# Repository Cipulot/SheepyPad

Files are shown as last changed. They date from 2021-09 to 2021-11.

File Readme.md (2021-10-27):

# SheepyPad

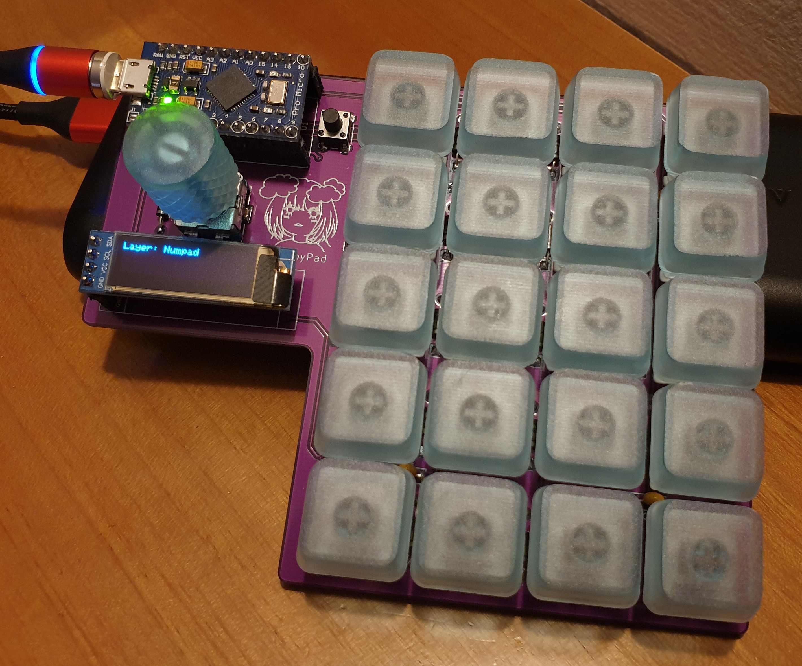
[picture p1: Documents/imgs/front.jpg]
SheepyPad


SheepyPad is an ISO Enter shaped macropad easy to build and customize.

Main features included:

- 5x4 key matrix (both 3-pin and 5-pin supported)
- 128x32 OLED display for status indication
- Rotary encoder for media control
- Integrated 2 operand calculator with basic math operations (+, -, *, /, sqrt)
- VIA and QMK compatibility
- 6 addressable RGB LEDs for underglow

## Guides

### QMK

This board fully supports QMK, refer to the [official docs](https://beta.docs.qmk.fm/).

### VIA

If you wanna use VIA follow the instructions [here](https://github.com/Cipulot/SheepyPad/blob/main/Documents/via.md).

### Calculator

SheepyPad implements a simple calculator that you can use to perform basic math operations. Follow the [Calculator Guide](https://github.com/Cipulot/SheepyPad/blob/main/Documents/calculator.md) to get started.

### PCB

Follow the [PCB Assembly Instructions](https://github.com/Cipulot/SheepyPad/blob/main/Documents/pcb_assembly.md) to build the PCB and test it out.

## Repo structure

- `Docs` contains all documentation and images for the project.
- `Firmware` contains both the source and precompiled binaries.
- `Hardware` contains the KiCad design files for the keyboard, fabrication files (in the [Gerbers](https://github.com/Cipulot/SheepyPad/blob/main/Hardware/Gerbers) folder).
- `Mechanicals` contains STEP file of the PCB and components, plate and case files.

## Project status

Project is currently in development. V1 boards have been produced and tested successfully. V2 boards are in the works and will add/change currently available features (both hardware and firmware wise).

Software is in constant change and being updated on my qmk_firmware fork available [here](https://github.com/Cipulot/qmk_firmware). You can find a basic default code example (with precompiled binaries) in this repo too if you want to quickly get it up and running.

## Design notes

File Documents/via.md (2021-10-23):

# VIA Keymap Configuration

VIA is a great way to quickly configure both keymap and lighting for the SheepyPad. Rather than modify code, recompile and then flash the binary, you can simply change the keymap and lighting settings in the graphical editor.

## Install VIA

To use VIA, first [download and install](https://caniusevia.com/) the configuration software.

After that you'll need to go to the `Settings` tab and select `Show Design tab` as shown here:

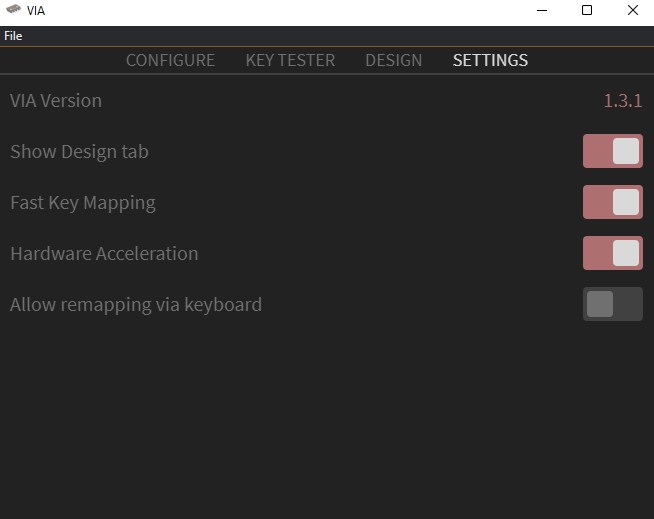
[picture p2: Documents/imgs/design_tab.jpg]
DesignTab


After that the `Design` tab will appear on the top center of the VIA window.

Now click on it and you'll be presented with this window:

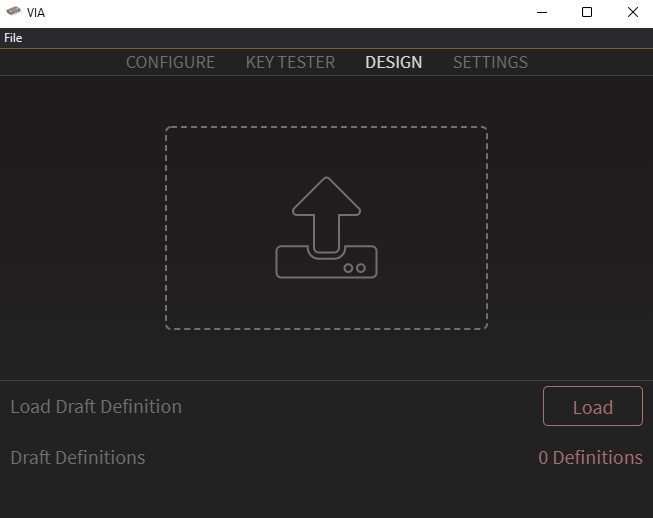
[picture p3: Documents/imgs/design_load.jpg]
DesignLoad


Click on either `Load` or the big icon in the center of the window to load the SheepyPad definition `json` file. This file is located in the `Firmware` folder, the [info.json](https://github.com/Cipulot/SheepyPad/blob/main/Firmware/info.json) file to be specific.

If everything loaded correctly you're gonna see something like this:

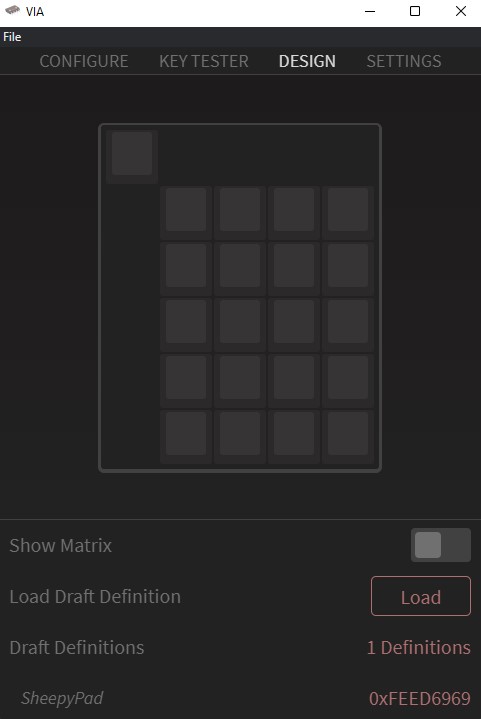
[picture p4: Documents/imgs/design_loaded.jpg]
DesignLoaded


**Note: in order to edit the keymap and lighting you MUST follow the procedure listed above. VIA does not automatically recognize SheepyPad.**

## Configure Keys

From within VIA, you can easily configure keys as you please. It allows you to change the default keymap to whatever suits your needs. Every key (with **one exemption** shown later) on every layer can be reconfigured.

The default configuration is as follows:

- Numberpad
- Empty Macro ---> here you have the freedom to assign macros or whatever you want
- Calculator  ---> here the keys have custom coded keycodes that are not standard
- Adjust      ---> here you have all the QMK keycodes to control lighting and other features

**It does not however allow you to configure the rotary encoder behavior......yet, a workaround is in the making but for now you'll need to configure them through QMK**.

### Exemption

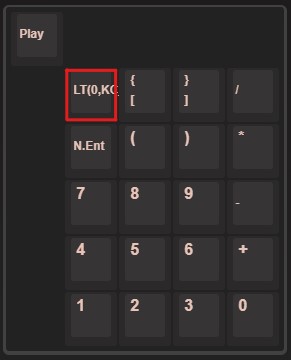
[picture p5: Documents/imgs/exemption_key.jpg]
ExemptionKey


In order to switch layer in a "cycle style" this key is used. Changing the layer is done by pressing this key repeatedly. Changing it using VIA will probably cause the board to be stuck in the last layer selected untill the board is unpluggged and replugged. This is a known thing and will be changed in the future.

## Configure Encoders

By default, the encoders are configured to volume up / down (on every layer).

Unfortunately, due to limitations in VIA the encoders are not visible or configurable. The best workaround at this time is to build a new VIA keymap with the encoder functions altered to suit your use case, flash this onto the board, and then configure the remainder of the keys in VIA. This can be done by following the below instructions:

- Follow the QMK [getting started guide](https://docs.qmk.fm/#/newbs_getting_started) to install the toolchain and configure your build environment.
- Open the `../via/keymap.c` file in your preferred text editor.
- Locate the function `encoder_update_user`, and update the keycodes in `tap_code(KC_xxx)` to one from the [keycodes list](https://beta.docs.qmk.fm/using-qmk/simple-keycodes/keycodes). If you use keycode not on the basic list, you may need to replace `tap_code` with `tap_code16`.
- With the changes made, save your new keymap, build, and flash the keymap to SheepyPad.
- You should now see the encoders functioning as desired, and you can configure the remainder or your keyboard using VIA.

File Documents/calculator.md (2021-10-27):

# Calculator Guide

The calculator is integrated and can be accessed by toggling the layer key until you see the following on the OLED screen:

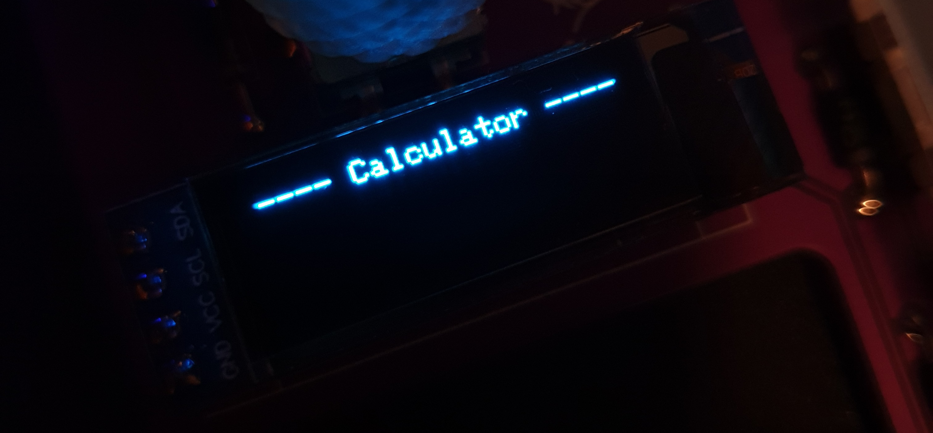
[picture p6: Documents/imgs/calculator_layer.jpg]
CalculatorLayer


From here the key matrix acts as the input method for the calculator, following this mapping:

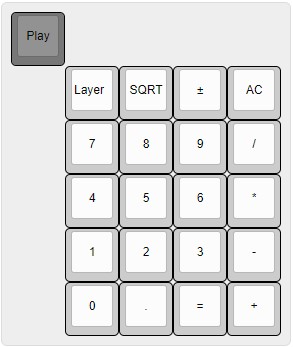
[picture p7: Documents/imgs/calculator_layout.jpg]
CalculatorLayout


## Supported operands and operations

The calculator supports 2 operands , called `term_1` and `term_2` in the code (for reference). A series of checks is implemented so that the state of the calculator is always valid.

### 4 basic operations and signs

The input flow is as follows for the 4 basic operations:

1. user enters digits for `term_1`

    1.1 user presses `±` to change `term_1` sing

2. user selects an operation `+` , `-` , `*` or `/`

3. user enters digits for `term_2`

    3.1 user presses `±` to change `term_2` sing

4. user presses `=` to calculate the result

When the calculation result is displayed, the calculator will wait for the user to reset the state to the initial state via the `AC` key.

**Note:** if an operation is selected before any digit has being pressed the calculator treats `term_1` as a `0`. In this case when `*` or `/` is selected the return value will be `0` as the result. The indetermination case is also handled, returning `0`.

### Square Root

The `SQRT` function calculates the square root of the `term_1` operand by itself or the result of an operation between `term_1` and `term_2`. Therefore the `term_1` operand or the result of the operation between `term_1` and `term_2` must be a positive number, otherwise the calculator will display `Imaginary Root!` as a result.

The input flow is as follows:

**`term_1` only**

1. user enters digits for `term_1`

2. user presses `SQRT` to calculate the result

**`term_1` and `term_2`**

1. user enters digits for `term_1`

    1.1 user presses `±` to change `term_1` sing

2. user selects an operation `+` , `-` , `*` or `/`

3. user enters digits for `term_2`

    3.1 user presses `±` to change `term_2` sing

4. user presses `SQRT` to calculate the result, evaluated as `sqrt( term_1|operand|term_2)`

As for the 4 basic operations, when the calculation result is displayed, the calculator will wait for the user to reset the state to the initial state via the `AC` key.

#### **Notes:**

~~* The `SQRT` function is not supported for `term_2` operands. If you try to execute one of the 4 basic operations and then press `SQRT` this won't produce any output (the `SQRT` command is ignored).~~

~~* Again if no digits are entered for `term_1` the calculator will treat it as a `0` and return `0` as the result if `SQRT` is pressed.~~

~~**Implementation of the `SQRT` function as above (`term1` → `operation` → `term__2` → `SQRT`) is in the work.**~~

## Implementation status

This table summarize the implementation status of the calculator.

| **Legend:**  | ✅ Supported | 🚧 Under Development | 💡 Planned |
|-|-|-|-|

| Feature | Status |
|:---:|:---:|
| `+` | ✅ |
| `-` | ✅ |
| `*` | ✅ |
| `/` | ✅ |
| `±` | ✅ |
| `AC` | ✅ |
| `SQRT` | ✅ |
| `C` | 💡 |
| `.` aka decimal operands | 🚧 |

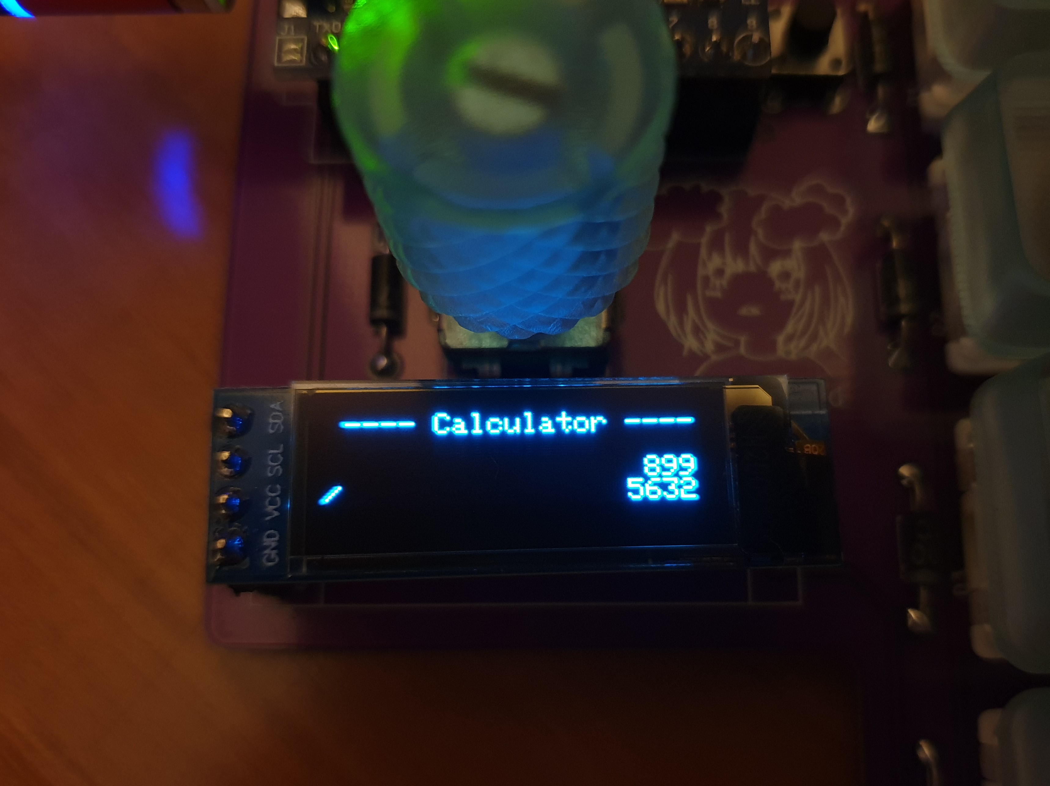
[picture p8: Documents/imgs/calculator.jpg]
Calculator


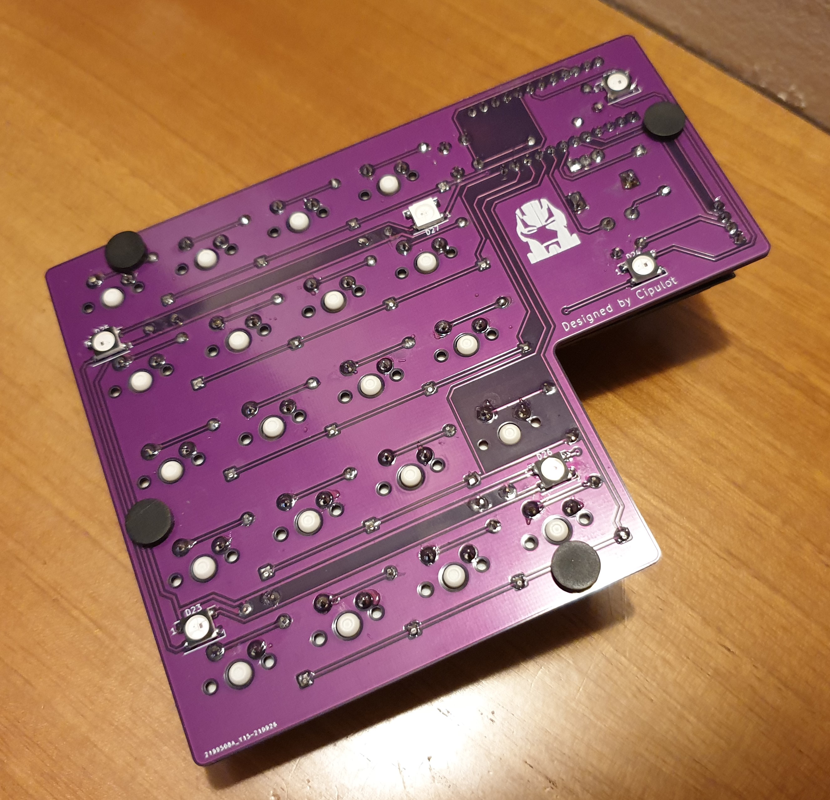
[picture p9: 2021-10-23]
Documents/imgs/back.jpg

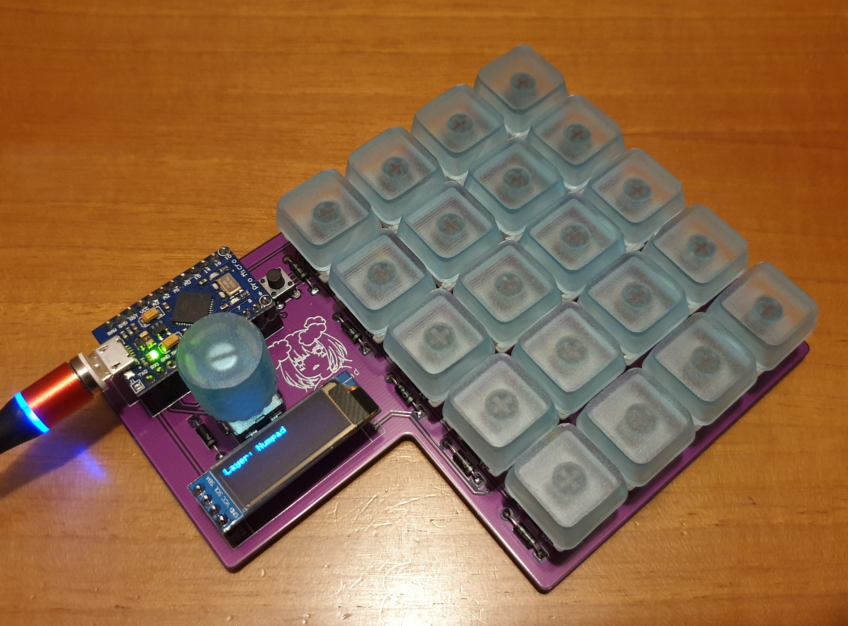
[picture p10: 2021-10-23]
Documents/imgs/front_2.jpg

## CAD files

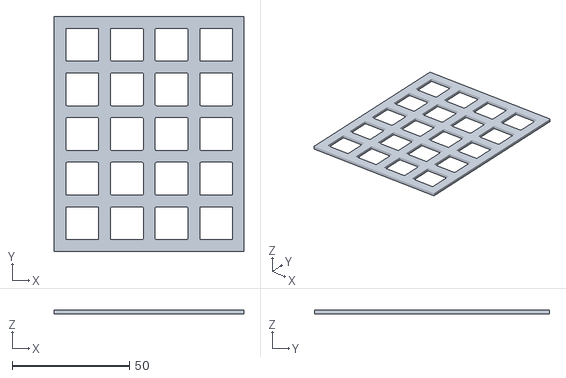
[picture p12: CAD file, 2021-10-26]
Mechanicals/plate_mx_only.stl
81.1 x 100.3 x 1.60

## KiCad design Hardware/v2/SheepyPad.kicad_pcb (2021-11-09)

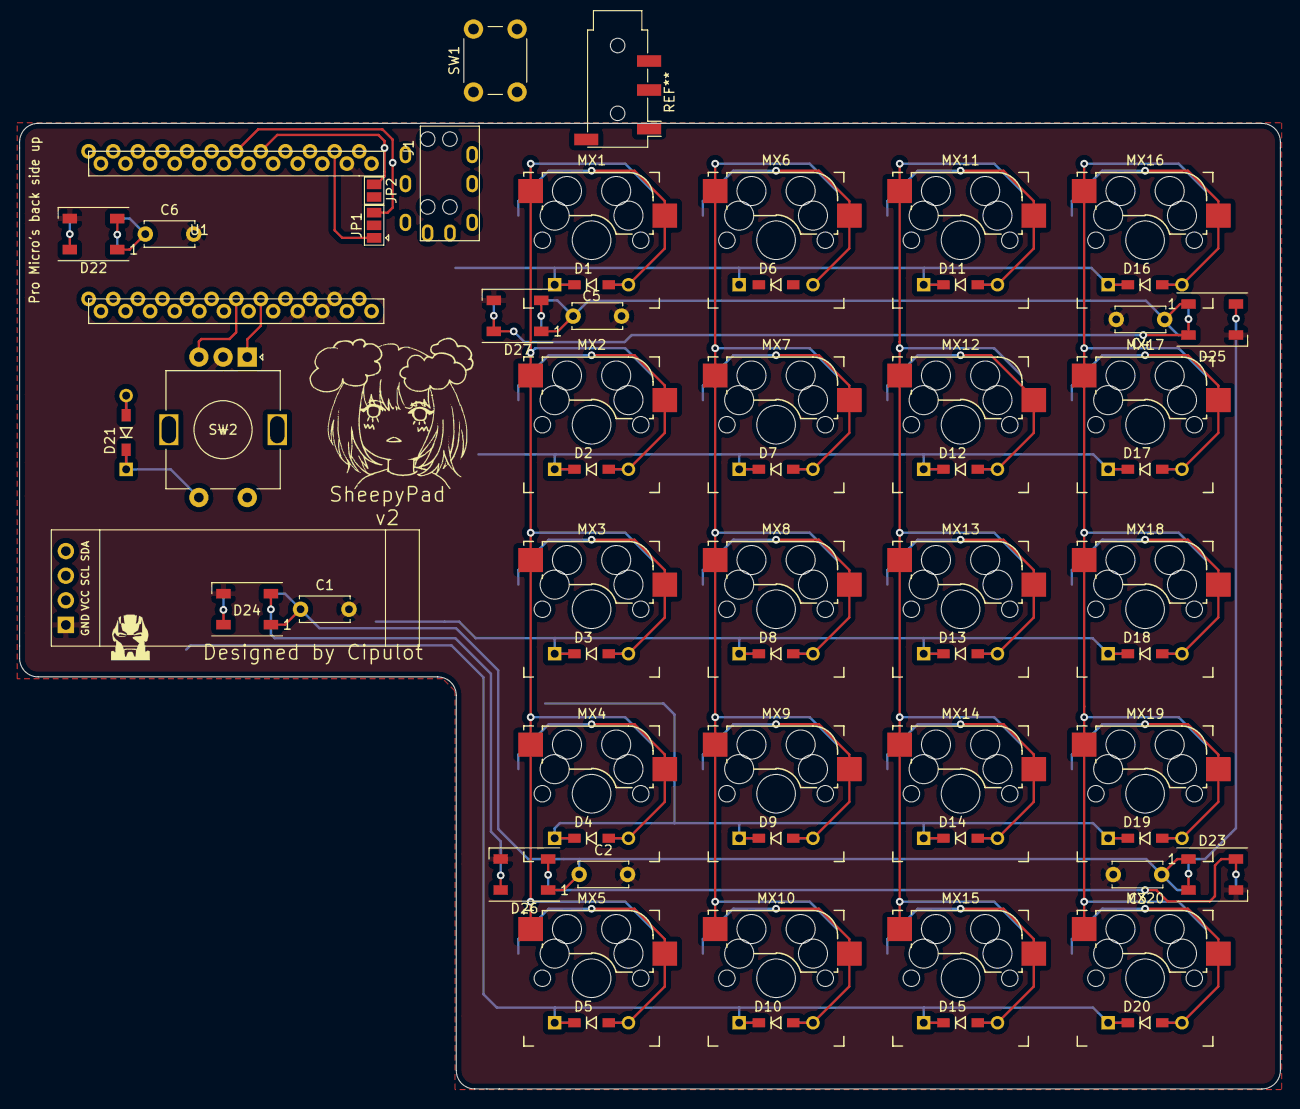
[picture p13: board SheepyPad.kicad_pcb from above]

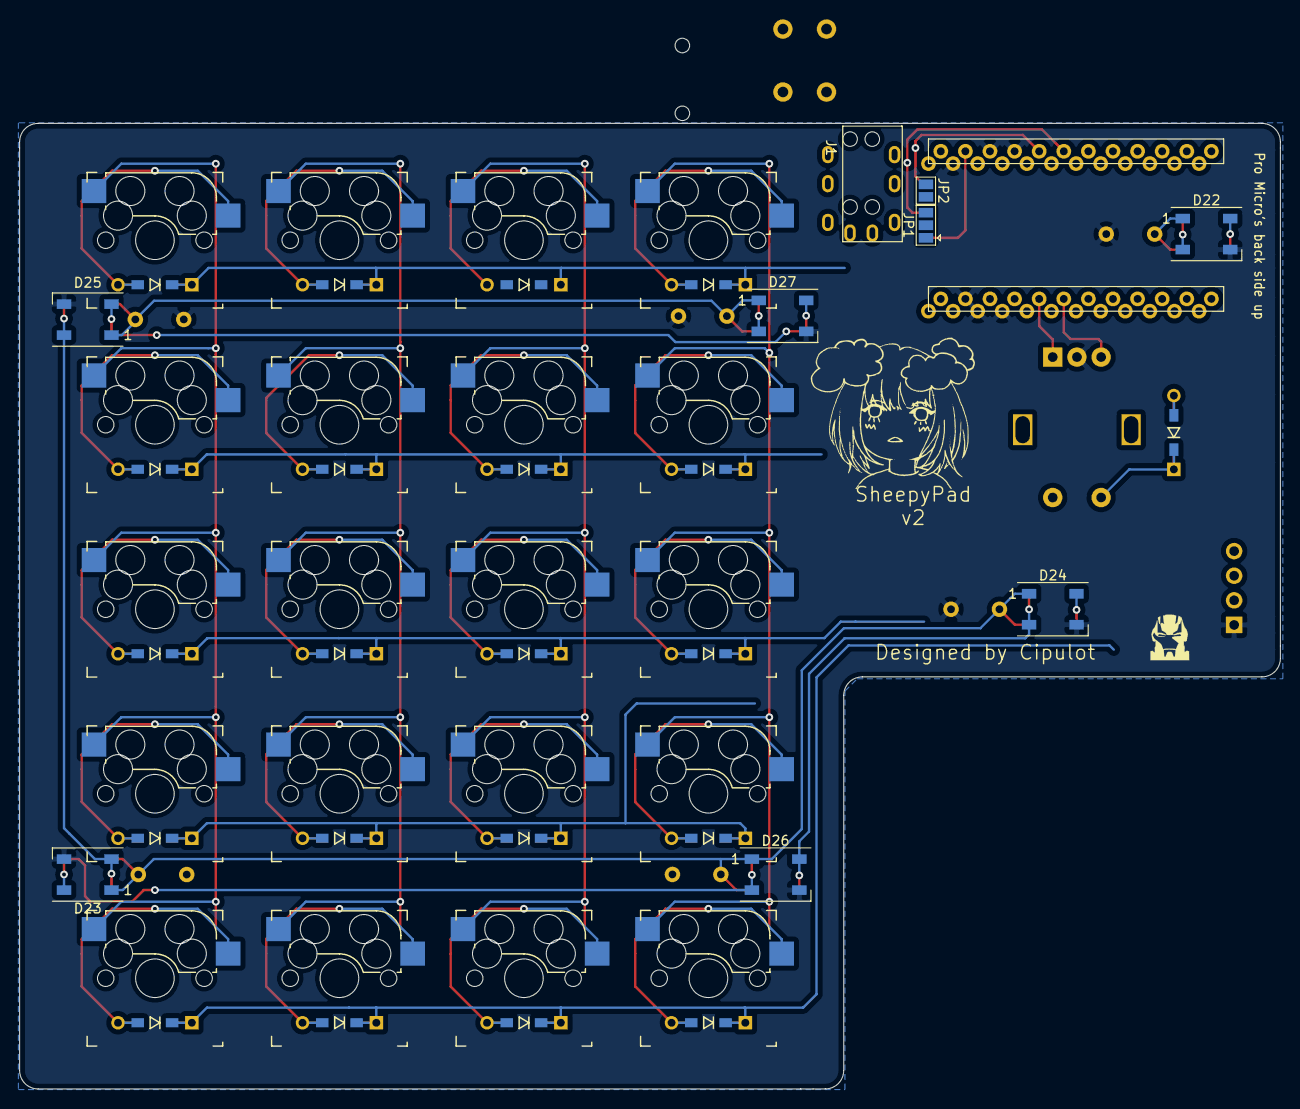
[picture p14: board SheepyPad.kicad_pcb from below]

Board: 2 copper layers, 130.2 x 99.7 mm, 69 parts (9 on the bottom side), 46 nets.

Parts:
Brd1: SSD1306; SSD1306-0.91-OLED-4pin-128x32
C1, C2, C3, C4, C5, C6: 100n; C_Disc_D5.0mm_W2.5mm_P5.00mm
D1, D2, D3, D4, D5, D6, D7, D8, D9, D10, D11, D12, D13, D14, D15, D16, D17, D18, D19, D20, D21: D_Small; Diode_SMD_THT_DUAL
D22, D22#2, D23, D23#2, D24, D24#2, D25, D25#2, D26, D26#2, D27, D27#2: WS2812B; LED_WS2812B_PLCC4_5.0x5.0mm_P3.2mm
J1, J1#2: AudioJack4; PJ-3200B-4A
JP1, JP1#2: Serial/SCL Jumper; SolderJumper-3_P1.3mm_Open_Pad1.0x1.5mm
JP2, JP2#2: SDA Jumper; SolderJumper-2_P1.3mm_Open_Pad1.0x1.5mm
MX1, MX2, MX3, MX4, MX5, MX6, MX7, MX8, MX9, MX10, MX11, MX12, MX13, MX14, MX15, MX16, MX17, MX18, MX19, MX20: MX-NoLED; Kailh_socket_MX_optional_reversible_FLIP
SW1: SW_Push; SW_PUSH_6mm
SW2: Rotary_Encoder_Switch; RotaryEncoder_Alps_EC11E-Switch_Vertical_H20mm
U1: Sparkfun_Pro_Micro; Sparkfun_Pro_Micro_reversible

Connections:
/COL_0: D21.2, U1.13
/COL_1: MX1.1, MX2.1, MX3.1, MX4.1, MX5.1, U1.14
/COL_2: MX6.1, MX7.1, MX8.1, MX9.1, MX10.1, U1.15
/COL_3: MX11.1, MX12.1, MX13.1, MX14.1, MX15.1, U1.16
/COL_4: MX16.1, MX17.1, MX18.1, MX19.1, MX20.1, U1.17
/DATA: JP1#2.1, U1.2
/ENC_A: SW2.A, U1.20
/ENC_B: SW2.B, U1.19
/GLOW_LED: D22.4, D22#2.4, U1.7
/RESET: SW1.2, U1.22
/ROW_0: D1.1, D6.1, D11.1, D16.1, SW2.S2, U1.12
/ROW_1: D2.1, D7.1, D12.1, D17.1, U1.11
/ROW_2: D3.1, D8.1, D13.1, D18.1, U1.10
/ROW_3: D4.1, D9.1, D14.1, D19.1, U1.9
/ROW_4: D5.1, D10.1, D15.1, D20.1, U1.8
/SCL: Brd1.3, JP1#2.3, U1.6
/SDA: Brd1.4, JP2#2.1, U1.5
GND: Brd1.1, C1.2, C2.2, C3.2, C4.2, C5.2, C6.2, D22.3, D22#2.3, D23.3, D23#2.3, D24.3, D24#2.3, D25.3, D25#2.3, D26.3, D26#2.3, D27.3, D27#2.3, SW1.1, SW2.C, U1.3, U1.4, U1.23
unnamed: D1.2, MX1.2
unnamed: D2.2, MX2.2
unnamed: D3.2, MX3.2
unnamed: D4.2, MX4.2
unnamed: D5.2, MX5.2
unnamed: D6.2, MX6.2
unnamed: D7.2, MX7.2
unnamed: D8.2, MX8.2
unnamed: D9.2, MX9.2
unnamed: D10.2, MX10.2
unnamed: D11.2, MX11.2
unnamed: D12.2, MX12.2
unnamed: D13.2, MX13.2
unnamed: D14.2, MX14.2
unnamed: D15.2, MX15.2
unnamed: D16.2, MX16.2
unnamed: D17.2, MX17.2
unnamed: D18.2, MX18.2
unnamed: D19.2, MX19.2
unnamed: D20.2, MX20.2
unnamed: D21.1, SW2.S1
unnamed: D22.2, D22#2.2, D24.4, D24#2.4
unnamed: D23.2, D23#2.2, D25.4, D25#2.4
unnamed: D23.4, D23#2.4, D26.2, D26#2.2
unnamed: D24.2, D24#2.2, D26.4, D26#2.4
unnamed: D25.2, D25#2.2, D27.4, D27#2.4
unnamed: D27.2, D27#2.2
VCC: Brd1.2, C1.1, C2.1, C3.1, C4.1, C5.1, C6.1, D22.1, D22#2.1, D23.1, D23#2.1, D24.1, D24#2.1, D25.1, D25#2.1, D26.1, D26#2.1, D27.1, D27#2.1, U1.21

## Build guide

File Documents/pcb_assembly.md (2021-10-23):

# PCB Assembly Instructions

This doc will guide you through the procedures for assembling the SheepyPad PCB.

Before assembling the board, ensure you have all of the required parts.

* SheepyPad PCB
* 1 * Ardiuno Pro Micro ATmega32U4
* 1 * 128x32 OLED display (with complementary male 4-pin strip)
* 1 * Rotary encoders (EC11-type supported)
* 1 * Rotary encoder knob
* 1 * Mini Push Button Switch 4-pin
* 21 * diodes
* 6 * 100nF Ceramic Capacitors
* 6 * WS2812B LEDs
* Rubber feet
* 20 * Cherry MX Key Switches (not shown)
* 20 * 1U Cherry MX Keycaps (not shown)

You will also require the following tools (for the soldered version of the PCB):

* Soldering iron and solder

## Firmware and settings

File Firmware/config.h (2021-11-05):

#pragma once

#include "config_common.h"

/* USB Device descriptor parameter */
#define VENDOR_ID       0xFEED
#define PRODUCT_ID      0x6969
#define DEVICE_VER      0x0001
#define MANUFACTURER    Cipulot
#define PRODUCT         SheepyPad
#define DESCRIPTION     ISO Enter Shaped Macropad w/ OLED

/* key matrix size */
#define MATRIX_ROWS 6
#define MATRIX_COLS 5

/* key matrix pins */
#define MATRIX_ROW_PINS { C6, F7, B5, B4, E6, D7 }
#define MATRIX_COL_PINS { D4, B1, B3, B2, B6 }
#define UNUSED_PINS

/* COL2ROW or ROW2COL */
#define DIODE_DIRECTION COL2ROW


/* Set 0 if debouncing isn't needed */
#define DEBOUNCING_DELAY 5

/* ENCODER THINGS */
// #define ENCODER_DIRECTION_FLIP
// #define ENCODER_RESOLUTION
#define ENCODERS_PAD_A { D3 }
#define ENCODERS_PAD_B { D2 }

#define RGB_DI_PIN F6
#define RGBLED_NUM 6
#define RGBLIGHT_HUE_STEP 8
#define RGBLIGHT_SAT_STEP 8
#define RGBLIGHT_VAL_STEP 8
#define RGBLIGHT_LIMIT_VAL 255 /* The maximum brightness level */

#define RGBLIGHT_ANIMATIONS

#define OLED_DISPLAY_128X32

#define DYNAMIC_KEYMAP_LAYER_COUNT 4

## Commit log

2021-09-14 Initialized and added project
    [SheepyPad.kicad_pcb, SheepyPad.sch]
2021-09-14 Add project specific lib in KiCad project
2021-09-14 Gerber files output
    [SheepyPad-B_Cu.gbl, SheepyPad-B_Mask.gbs, SheepyPad-B_SilkS.gbo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]
2021-09-15 Various Updates
    [SheepyPad-B_CrtYd.gbr, SheepyPad-B_Cu.gbl, SheepyPad-B_Fab.gbr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]
2021-09-15 Changes
    - Updated silkscreen logos
    - Updated tracks
    [SheepyPad-B_CrtYd.gbr, SheepyPad-B_Cu.gbl, SheepyPad-B_Fab.gbr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]
2021-09-16 Updates
    - Updates nets (again)
    - Updated gerber files for production
    [SheepyPad-B_CrtYd.gbr, SheepyPad-B_Cu.gbl, SheepyPad-B_Fab.gbr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]
2021-09-25 Update fabrication
    [SheepyPad-B_CrtYd.gbr, SheepyPad-B_Cu.gbl, SheepyPad-B_Fab.gbr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]
2021-09-27 Repo formatting
    Added folder in prevision of future additions
    [SheepyPad-B_CrtYd.gbr, SheepyPad-B_Cu.gbl, SheepyPad-B_Fab.gbr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]
2021-09-28 Fixed Diode orientation for encoder SW
    [SheepyPad-B_CrtYd.gbr, SheepyPad-B_Cu.gbl, SheepyPad-B_Fab.gbr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]
2021-10-02 Various changes
    info.json: Modified keymap layout for proper VIA recognition.
    sheepypad.h: modified LAYOUT to reflect matrix wiring and blanks.
    keymap.c: fixed keymap and added primitive calculator features
2021-10-23 Boards images upload
2021-10-26 Moved file around
    [plate_mx_only.stl]
2021-10-27 Addition of function to handle result print
2021-11-04 File move for v2
    [SheepyPad-B_CrtYd.gbr, SheepyPad-B_Cu.gbl, SheepyPad-B_Fab.gbr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]
2021-11-04 Add of personal KiCad submodule
2021-11-04 Remove of redundant lib
    [SheepyPad.kicad_pcb, SheepyPad.sch]
2021-11-05 WIP v2
    [SheepyPad.kicad_pcb, SheepyPad.sch]
2021-11-05 Update v2
    [SheepyPad.kicad_pcb, SheepyPad.sch]
2021-11-05 PCB update
